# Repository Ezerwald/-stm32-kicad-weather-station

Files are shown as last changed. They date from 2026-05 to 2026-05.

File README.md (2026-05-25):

# STM32 KiCad Weather Station

KiCad-based PCB project for an STM32-powered IoT weather station with environmental sensing, real-time clock support, battery charging, and e-paper display connectivity.

> 3D render:


## Overview

This project is a custom two-layer PCB designed in KiCad for a compact embedded weather station.  
The board is built around the **STM32F103C8T6** microcontroller and integrates power management, sensing, display, and timekeeping components into a single design.

The main goal of the project was to practice the complete PCB design workflow: schematic capture, component selection, board layout, and preparation of production files.

## Main features

- STM32F103C8T6 microcontroller
- BME280 environmental sensor
- DS3231S real-time clock
- E-paper display connector
- TP4056 Li-ion battery charging circuit
- AMS1117-3.3 voltage regulator
- USB-C power input
- 5 control buttons
- Status LEDs

## Hardware components

### Core components
- **U1** — STM32F103C8T6
- **U2** — BME280
- **U3** — TP4056
- **U4** — AMS1117-3.3
- **U5** — DS3231S

### Connectors and interfaces
- **P1** — USB_C_Plug
- **J1** — Battery
- **J2** — Prog
- **J3** — E-Paper_Display

### User interface
- **SW1–SW5** — buttons
- **D1** — Blue LED
- **D2** — Green LED
- **D3** — Red LED

## Design files

> Schematic:


> PCB layout:


## Notes

This repository focuses mainly on the PCB design itself rather than firmware implementation.  
The project includes the main design files, screenshots, and fabrication outputs for documentation purposes.

## Tools used

- **KiCad** for schematic and PCB design
- Optional 3D viewer/export from KiCad for board rendering

## Author

**Vladyslav Kyshchun**

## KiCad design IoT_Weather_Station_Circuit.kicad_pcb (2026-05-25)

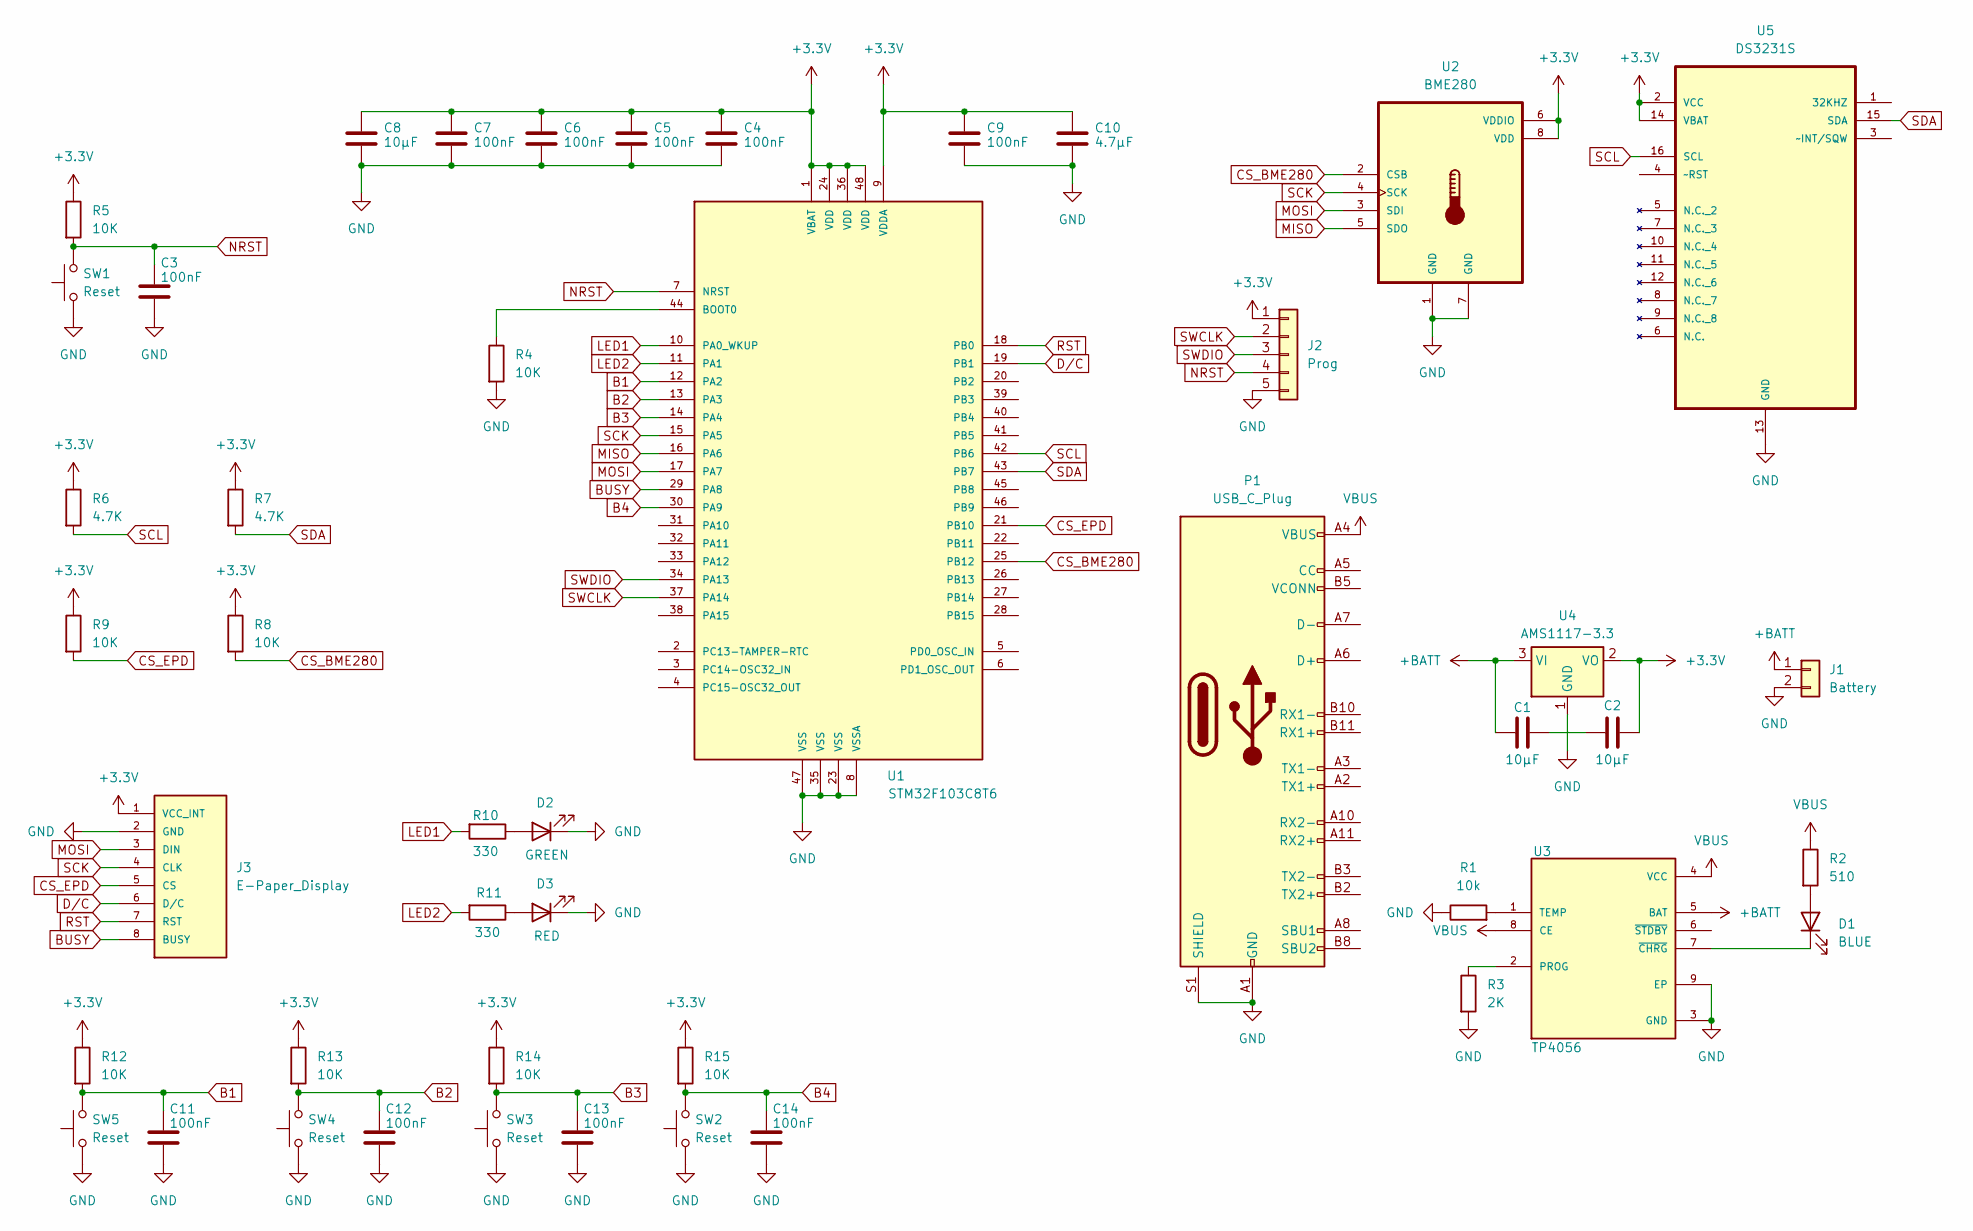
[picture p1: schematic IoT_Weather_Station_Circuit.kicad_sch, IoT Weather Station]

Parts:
C1, C2: 10µF; C_0201_0603Metric
C3, C4, C5, C6, C7, C9, C11, C12, C13, C14: 100nF; C_0603_1608Metric
C8: 10µF; C_0603_1608Metric
C10: 4.7µF; C_0603_1608Metric
D1: BLUE; LED_0603_1608Metric
D2: GREEN; D_0201_0603Metric
D3: RED; D_0201_0603Metric
J1: Battery; JST_EH_B2B-EH-A_1x02_P2.50mm_Vertical
J2: Prog; JST_EH_B5B-EH-A_1x05_P2.50mm_Vertical
J3: E-Paper_Display; AMPHENOL_59453-081110ECHLF; PARTREV A
P1: USB_C_Plug; USB_C_Plug_Molex_105444
R1: 10k; R_0603_1608Metric
R2: 510; R_0603_1608Metric
R3: 2K; R_0603_1608Metric
R4, R5, R8, R9, R12, R13, R14, R15: 10K; R_0603_1608Metric
R6, R7: 4.7K; R_0603_1608Metric
R10, R11: 330; R_0603_1608Metric
SW1, SW2, SW3, SW4, SW5: Reset; SW_Push_1P1T_NO_6x6mm_H9.5mm
U1: STM32F103C8T6; STM-32F103C8T6; PARTREV 10
U2: BME280
U3: TP4056
U4: AMS1117-3.3; SOT-223-3_TabPin2
U5: DS3231S; MPN DS3231S#; DigiKey_Part_Number DS3231S#-ND

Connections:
+3.3V: C2.1, C4.1, C5.1, C6.1, C7.1, C8.1, C9.1, C10.1, J2.1, J3.1 (VCC_INT), R5.1, R6.1, R7.1, R8.1, R9.1, R12.1, R13.1, R14.1, R15.1, U1.1 (VBAT), U1.9 (VDDA), U1.24 (VDD), U1.36 (VDD), U1.48 (VDD), U2.6 (VDDIO), U2.8 (VDD), U4.2 (VO), U5.2 (VCC), U5.14 (VBAT)
+BATT: C1.2, J1.1, U3.5 (BAT), U4.3 (VI)
B1: C11.1, R12.2, SW5.2, U1.12 (PA2)
B2: C12.1, R13.2, SW4.2, U1.13 (PA3)
B3: C13.1, R14.2, SW3.2, U1.14 (PA4)
B4: C14.1, R15.2, SW2.2, U1.30 (PA9)
BUSY: J3.8 (BUSY), U1.29 (PA8)
CS_BME280: R8.2, U1.25 (PB12), U2.2 (CSB)
CS_EPD: J3.5 (CS), R9.2, U1.21 (PB10)
D/C: J3.6 (D/C), U1.19 (PB1)
GND: C3.2, C4.2, C5.2, C6.2, C7.2, C8.2, C9.2, C10.2, C11.2, C12.2, C13.2, C14.2, D2.1 (K), D3.1 (K), J1.2, J2.5, J3.2 (GND), P1.A1 (GND), P1.A12 (GND), P1.B1 (GND), P1.B12 (GND), P1.S1 (SHIELD), R1.1, R3.2, R4.2, SW1.1, SW2.1, SW3.1, SW4.1, SW5.1, U1.8 (VSSA), U1.23 (VSS), U1.35 (VSS), U1.47 (VSS), U2.1 (GND), U2.7 (GND), U3.3 (GND), U3.9 (EP), U4.1 (GND), U5.13 (GND)
LED1: R10.2, U1.10 (PA0_WKUP)
LED2: R11.2, U1.11 (PA1)
MISO: U1.16 (PA6), U2.5 (SDO)
MOSI: J3.3 (DIN), U1.17 (PA7), U2.3 (SDI)
NRST: C3.1, J2.4, R5.2, SW1.2, U1.7 (NRST)
unnamed: C1.1, C2.2
unnamed: D1.2 (A), R2.2
unnamed: D1.1 (K), U3.7 (~CHRG)
unnamed: D2.2 (A), R10.1
unnamed: D3.2 (A), R11.1
unnamed: R4.1, U1.44 (BOOT0)
unnamed: R3.1, U3.2 (PROG)
unnamed: R1.2, U3.1 (TEMP)
RST: J3.7 (RST), U1.18 (PB0)
SCK: J3.4 (CLK), U1.15 (PA5), U2.4 (SCK)
SCL: R6.2, U1.42 (PB6), U5.16 (SCL)
SDA: R7.2, U1.43 (PB7), U5.15 (SDA)
SWCLK: J2.2, U1.37 (PA14)
SWDIO: J2.3, U1.34 (PA13)
VBUS: P1.A4 (VBUS), P1.A9 (VBUS), P1.B4 (VBUS), P1.B9 (VBUS), R2.1, U3.4 (VCC), U3.8 (CE)

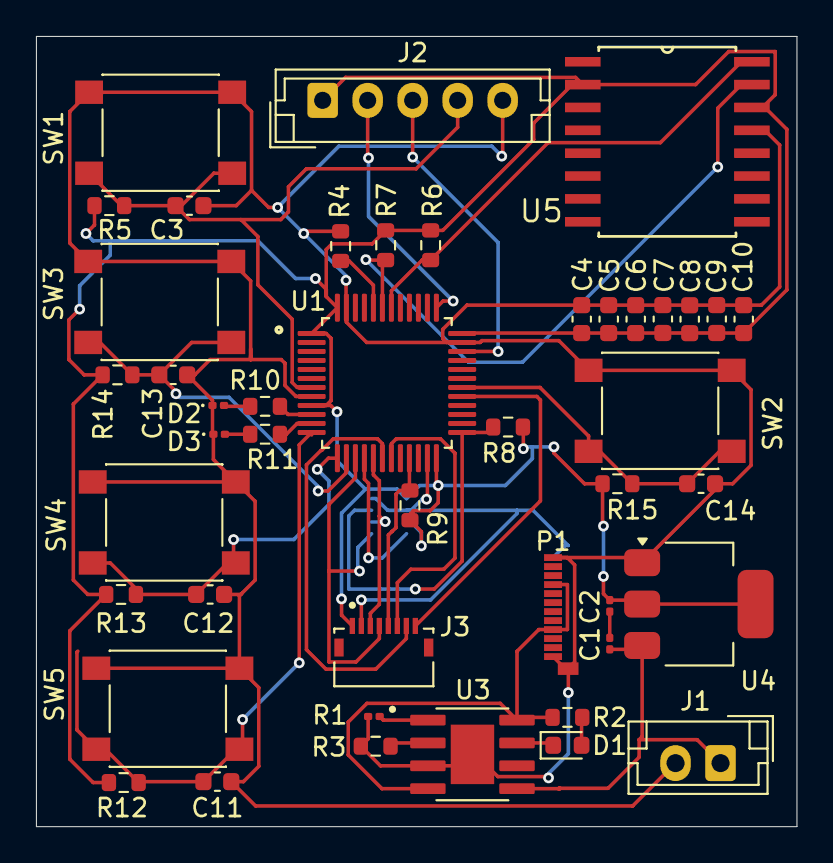
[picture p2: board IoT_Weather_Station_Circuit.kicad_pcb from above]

Board: 2 copper layers, 42.2 x 43.9 mm, 46 parts (1 on the bottom side), 31 nets.
